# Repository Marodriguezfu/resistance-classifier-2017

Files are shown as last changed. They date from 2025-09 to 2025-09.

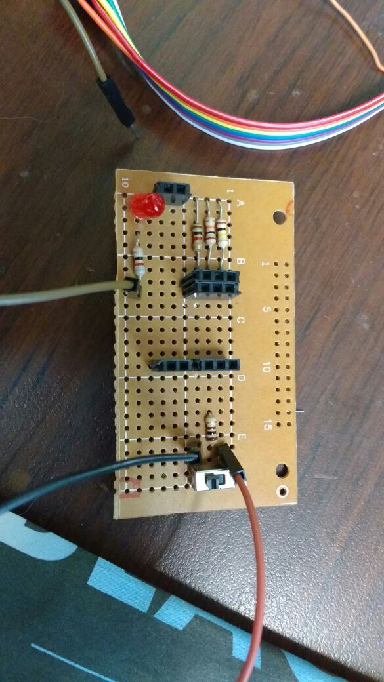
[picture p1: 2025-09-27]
images/Ima3.jpeg

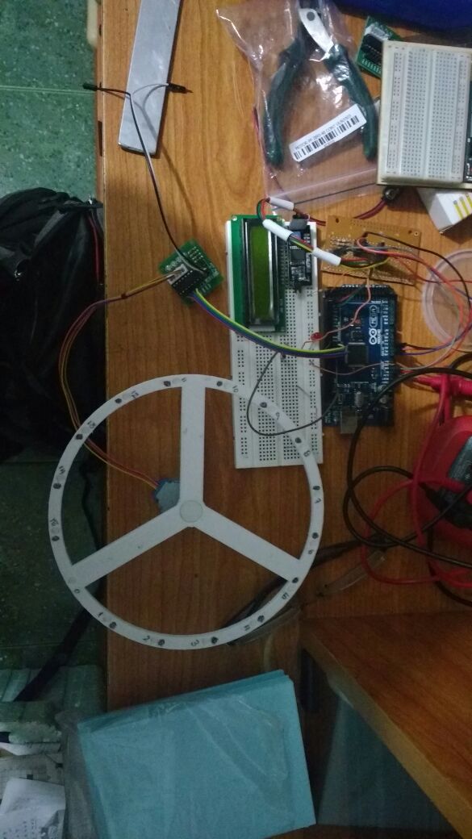
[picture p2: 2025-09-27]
images/Ima1.jpeg

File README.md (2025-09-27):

# Resistance Classifier (2017)

This repository contains the complete work of the **Resistance Classifier Project**, developed in 2017 as part of an engineering workshop at the **Universidad Nacional de Colombia**.  
The goal was to design and implement a device capable of **measuring and classifying resistors automatically** using **Arduino-based circuits**, **stepper motors**, and **3D-printed components**.

---

## 📖 Project Overview

Classifying resistors manually can be tedious due to their color bands and prone to human error (especially for people with visual impairments such as color blindness).  
This project proposed a compact device that could **feed, measure, and sort resistors** into dedicated containers:

1. **Feeding system** – a roller mechanism controlled by a motor that allows one resistor at a time to enter the measurement unit.  
2. **Measuring system** – based on an **Arduino ohmmeter** using voltage dividers and Ohm’s law.  
3. **Classification system** – a rotating rail controlled by a stepper motor, which directs the resistor into the correct bin according to its value.

---

## 🛠️ Features

- Arduino-based ohmmeter to calculate resistor values.  
- Automatic range detection (100 Ω – 820 kΩ).  
- Stepper motor precision control for classification.  
- Mechanical design of roller, rail, and box using **SolidWorks** and intended for 3D printing.  
- LCD display for showing measured resistance and assigned bin.  

---

## 📂 Repository Structure
```
resistance-classifier-2017/
│
├── src/ # Arduino source code
├── docs/ # Reports, guides, and project proposal (PDFs)
├── cad/ # CAD designs (SolidWorks)
├── figures/ # Images, diagrams, and results
├── README.md # Project documentation
└── .gitignore
```

## 📑 Documentation

The full documentation is provided in the `docs/` folder:
- **Project Proposal** – initial justification, design, and planning.  
- **Guides 1–3** – experimental steps with Arduino ohmmeter, CAD design, and stepper.  
- **Reports 1–3** – results of each stage (measurement ranges, CAD design, motor control).  
- **Final Report** – complete description of the device, final assembly, and conclusions.
---

## ⚙️ Hardware & Software Requirements

- **Hardware**
  - Arduino UNO (or compatible board)
  - Breadboard, jumpers, and resistors
  - Stepper motor (28BYJ-48) + ULN2003 driver
  - LCD display
  - 3D-printed mechanical parts (roller, box, rail)

- **Software**
  - Arduino IDE
  - SolidWorks (for CAD design)

---

## 🚀 How to Run

1. Connect the circuit as described in the `docs/Informe Final.pdf`.  
2. Open the Arduino IDE and upload the source code from `src/`.  
3. Place resistors into the roller mechanism.  
4. The system will measure and classify each resistor, showing results on the LCD.  

---

## 📊 Results

- Achieved automatic classification in ranges from **100 Ω up to 820 kΩ** with predefined tolerance.  
- Demonstrated integration of electronics, programming, and mechanical design.  
- Highlighted the importance of cost optimization in 3D printing (not all parts were fabricated).  

---

## 👥 Authors

- Julián Camilo Casallas Villamil  
- José Fernando Murcia Rincón  
- Daniel Camilo Peña Pabón  
- **Miguel Ángel Rodríguez Fuentes**  

Universidad Nacional de Colombia, 2017.

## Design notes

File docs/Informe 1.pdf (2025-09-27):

# Informe 1: Experimentación con el Óhmetro de Arduino

Casallas Villamil Julián Camilo, Murcia Rincón José Fernando, Peña Pabón Daniel Camilo, Rodríguez Fuentes Miguel Ángel
jcasallasv@unal.edu.co, jmurciar@unal.edu.co, dpenap@unal.edu.co, marodriguezfu@unal.edu.co

### Universidad Nacional de Colombia Grupo de Taller: 3 - Equipo de Trabajo: 4

I. RESUMEN

Con la primer práctica del clasificador de resistencias se busca establecer los rangos de funcionamiento del proyecto, así como los ajustes que se deben hacer a la idea original.

II. PALABRAS CLAVES

Divisor de voltaje, resistencias, Ley de Ohm, Arduino.

III. INTRODUCCIÒN

Empleando una placa de Arduino y dos resistencias es posible idear un óhmetro muy básico fundamentado en la ley de ohm y en el divisor de voltaje. Por medio de este óhmetro rudimentario, se pueden hacer mediciones básicas para algunas resistencias. Sin embargo, esto no es verídico para resistencias muy pequeñas o muy grandes.

IV. | MARCO TEÓRICO
1.1. Ley | de | Ohm:

Esta ley fundamental en electricidad y electrónica, establece la relación existente entre la tensión (V), la corriente (I) y la resistencia (R) donde esta primera es directamente proporcional a las dos siguientes. La fórmula general se escribe así:
V = I * R | (1)
1.2. Divisor | de | Voltaje
En un circuito eléctrico un divisor de voltaje (tensión) es el que reparte en una o más impedancias conectadas en serie la tensión de una fuente
El circuito de un divisor de voltaje se ve de esta manera:

Figura 1.

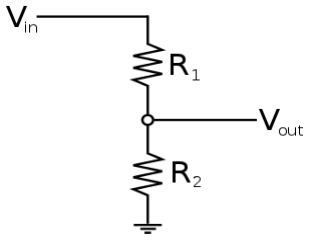
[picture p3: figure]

Esquema divisor de voltaje [1]

1.3. Introducción | básica | a | Arduino
Arduino puede referirse a las placas producidas por la compañía italiana homónima programables por su propio software (Arduino IDE). Estas placas vienen
equipadas | con | un | microcontrolador | o
microprocesador de arquitectura variable, varias entradas y/o salidas (E/S), analógicas y digitales. Estas dos anteriores características (arquitectura del CPU y cantidad de E/S) dependen del modelo del Arduino.[2]

El software necesario para controlar dichas placas (Arduino IDE) consiste de tres bloques de código el primero en el que se inicializan las variables del programa, el segundo (setup) que se ejecuta una sola vez que es donde se configuran los pines del Arduino y el tercero (loop) que se ejecuta perpetuamente es la parte funcional y lógica del código. A continuación se muestra el código para un led parpadeando en el Arduino.[2]

// the setup function runs once when you press reset or power the board
void setup | ( | ) {
// initialize digital pin LED_BUILTIN as an output. pinMode(LED_BUILTIN, OUTPUT);

}
// the loop function runs over and over again forever void loop() {
digitalWrite(LED_BUILTIN, HIGH); // turn the LED on (HIGH is the voltage level)
delay(1000); | // wait for a second
digitalWrite(LED_BUILTIN, LOW); // turn the LED of by making the voltage LOW
delay(1000); | // wait for a second
}
[3]

### Valores de Resistencias comerciales:

Banda 1 | Banda 2 | Banda 3
1 | 0
1 | 1
1 | 2
1 | 3
1 | 5
1 | 6
1 | 8
2 | 0
2 | 2
2 | 4
2 | 7
3 | 0
3 | 3
3 | 6
3 | 9
4 | 3
4 | 7
5 | 1
5 | 6
6 | 2

De 10

-1 a 10

6

6 | 8
7 | 5
8 | 2
9 | 1

### Tabla 1. Valores de resistencias comerciales

V. PARTE I: MONTAJE DEL CIRCUITO EN ARDUINO

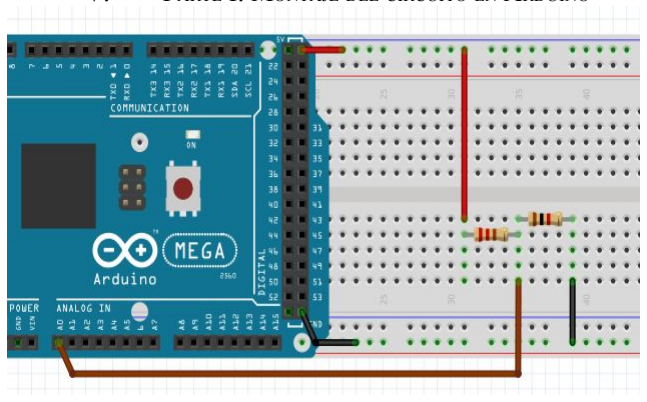
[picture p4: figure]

Figura 2. Montaje divisor de voltaje y Arduino

Tras realizar el montaje de las resistencias, lo que prosiguió fue la realización del código para calcular el valor de la resistencia. Para este cálculo, se emplea el siguiente código:

int analogPin = 0;

int raw = 0;

double Vin = 4.98;

double Vout = 0;

double R1 = 996;

double R2 = 0;

void setup () {

Serial.begin (9600);

}

void loop () {

raw = analogRead(analogPin);

if (raw) {

Serial.print("Raw: ");

Serial.println(raw);

Vout = 5 - ((raw*Vin) / 1023);

Serial.print ("Raw*Vin: ");

Serial.println (raw * Vin);

R2 = Vout/((Vin-Vout)/R1);

Serial.print("Vout: ");

Serial.println(Vout);

Serial.print("R2: ");

Serial.println(R2);

delay(1000);

}

}

VI. PARTE II: MEDICIÓN DE LOS VALORES MÍNIMOS

Una vez todo ensamblado, comenzamos a tomar resistencias variadas en los órdenes de 100 Ω a 1 M Ω , con resistencias fijas de 1000 Ω a 100000 Ω llegando así a la siguiente tabla:

Resistencia Fija ( Ω ) | Rango Mínimo ( Ω ) | Rango Máximo ( Ω )
1000 | 100 | 5600
10000 | 820 | 82000
100000 | 6800 | 820000
Tabla 2. Rangos Max y Min con resistencia fija.

con los valores obtenido en la tabla 2. podemos conocer de antemano los rangos bases con los que debemos trabajar en el proyecto.

VII. CONCLUSIONES:

- La utilización de un divisor de voltaje con un Arduino, resulta en mediciones imprecisas en los extremos del rango de resistencias comerciales.
- El limitar el rango de operación de un dispositivo es vital para un proceso de desarrollo sin baches.

VIII. REFERENCIAS

[1] L. Robert Boylestad, Introducción al análisis de circuitos, 12va ed.., Pearson Educación, 1998, pp. 348,354,355.
[2] D. Hugh Young, Física Universitaria, 13va ed., PEARSON, 2013, p.438.
[3] L. Thomas Floyd, Principios de circuitos eléctricos, 8va ed., PEARSON, 2007, p. 443.
[4] K. charles Alexander, Fundamentos de circuitos eléctricos, 3ra ed, Mc Graw Hill, p.176.

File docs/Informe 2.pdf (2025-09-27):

# Informe 2: Diseño estructura física clasificador de resistencias

Casallas Villamil Julián Camilo, Murcia Rincón José Fernando, Peña Pabón Daniel Camilo, Rodríguez Fuentes Miguel Ángel
jcasallasv@unal.edu.co, jmurciar@unal.edu.co, dpenap@unal.edu.co, marodriguezfu@unal.edu.co

### Universidad Nacional de Colombia Grupo de Taller: 3 - Equipo de Trabajo: 4

I. RESUMEN

Con esta segunda práctica pretendemos realizar el diseño para posterior impresión del clasificador de resistencias. Esto con el fin de mostrar un producto casi terminado para una posible comercialización o distribución del mismo

II. PALABRAS CLAVES

CAD, Impresión 3D

III. INTRODUCCIÒN

Dentro del campo de la ingeniería se hace casi imprescindible el uso de algún tipo de herramienta computacional con el fin de darle vida a los proyectos que se tienen en mente, en este caso hablamos del uso del CAD como herramienta de diseño en tercera dimensión con la cual realizaremos el diseño de la estructura del clasificador de resistencias.

IV. | MARCO TEÓRICO
1. Diseño | 3D:

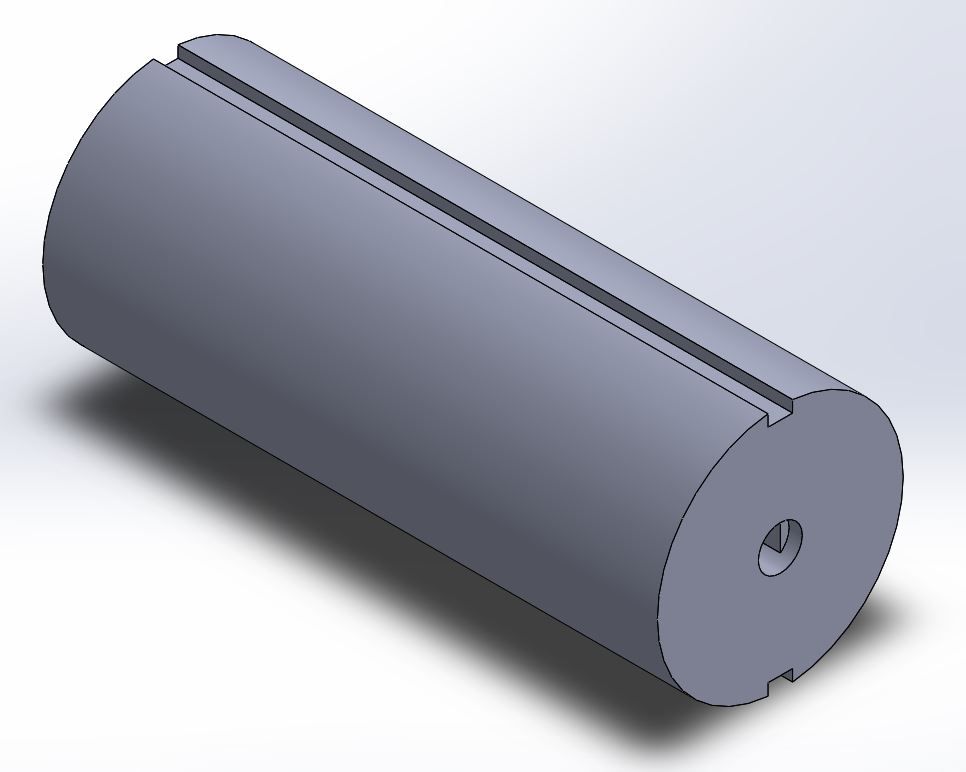
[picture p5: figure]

El diseño en 3D consiste en proporcionar a un objeto digital, creado mediante programas y softwares especiales para ello, las tres dimensiones (profundidad, anchura y longitud) que tiene todo elemento en la vida real. A la hora de realizarlo con los medios informáticos pertinentes y teniendo en cuenta su posterior impresión, el conformado de la pieza debe descomponerse en operaciones sencillas, optando por figuras geométricas básicas. Una vez se conoce el diseño que se quiere fabricar, hay dos opciones para hacer uso de él, en función de las necesidades que requiera el elemento.[1]
Actualmente encontramos en el mercado diversos software con la capacidad de realizar estos diseños asistidos, y entre los más comunes encontramos:
- AutoCAD
- 3D Max
- Sketchup
- SolidWorks

### 2. SolidWorks:

SolidWorks es un programa de diseño mecánico en 3D con el que se puede crear geometría 3D usando sólidos paramétricos, la aplicación está enfocada a diseño de producto, diseño mecánico, ensambles, y dibujos para taller. SolidWorks diseña de forma que va dejando un historial de operaciones para que puedas hacer referencia a ellas en cualquier momento.[2]

V. PARTE I: DISEÑO DEL RODILLO

La forma básica del rodillo es un cilindro con radio de 1 centímetro el cual irá ajustado en la caja principal del dispositivo a partir de un orificio de encaje. También tendrá por la otra cara el encaje para el motor.

Y finalmente el encaje para las resistencias que caerán de la caja y que posteriormente serán medidas a partir de los rangos medidos en el informe anterior.

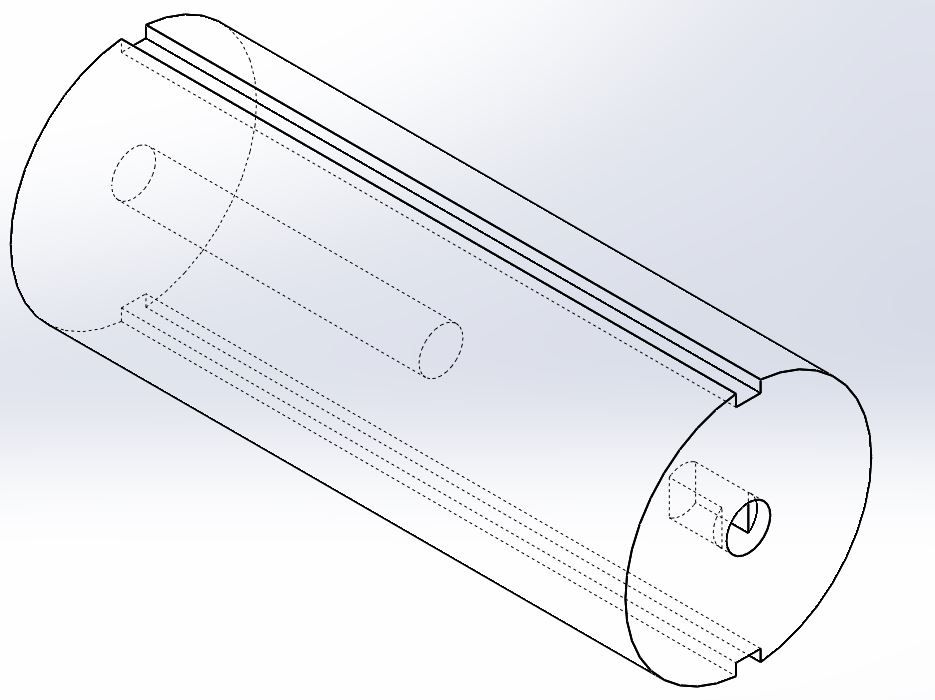
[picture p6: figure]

Figura 1. Forma Final del Rodillo

La figura anterior es el diseño finalizado del rodillo con las características que se necesitaban para llevar a cabo el proyecto. El costo aproximado de la impresión de este elemento es de $14800.

VI. PARTE II: DISEÑO CAJA

Para el diseño de la caja se empezó con la cubierta donde se encontraría el rodillo, la cual irá pegada a una recipiente donde se encontrarán las resistencias.

la cubierta del rodilla poseerá unos orificios los cuales servirán para poner en contacto las resistencias que allí se pongan con algún tipo de lámina conductora con el fin de completar el circuito y así realizar la medida de la resistencia.

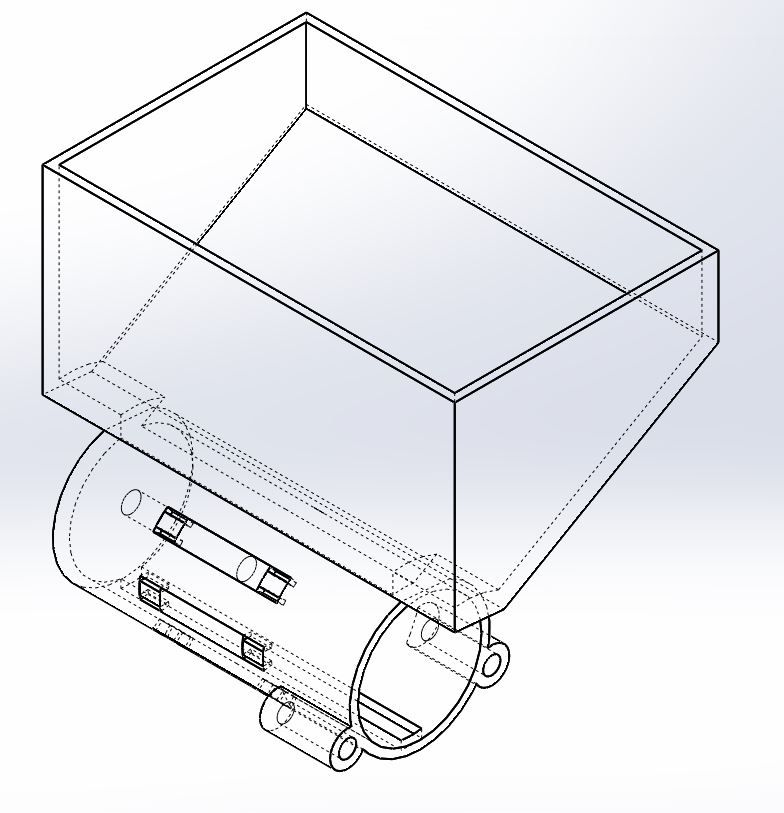
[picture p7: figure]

Figura 2. Forma Final de la caja

El costo aproximado de la impresión de este elemento es de $65500.

VII. PARTE III: DISEÑO DEL RIEL

El riel es la parte más fácil de realizar, solamente es una circunferencia de 9 cm de radio en la cual se dispondrán las distintas cajas.

Para realizar el ajuste más fácil al motor se dispuso de otro pequeño cilindro el cual será la conexión entre este y el riel.

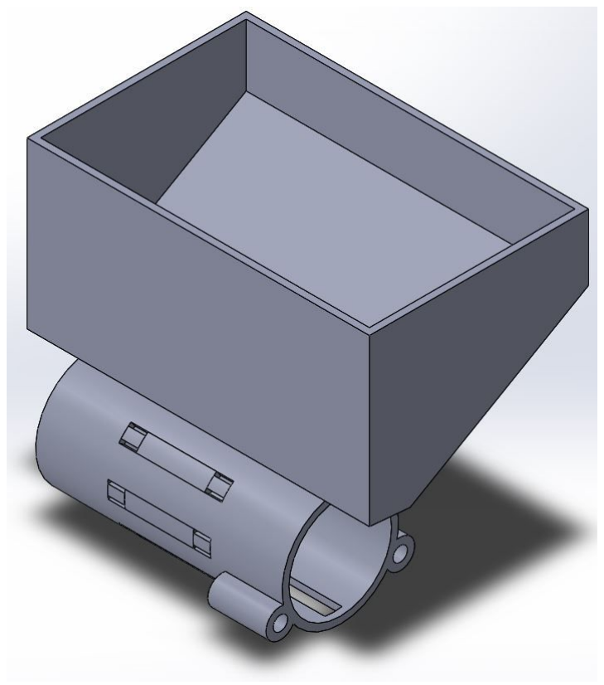
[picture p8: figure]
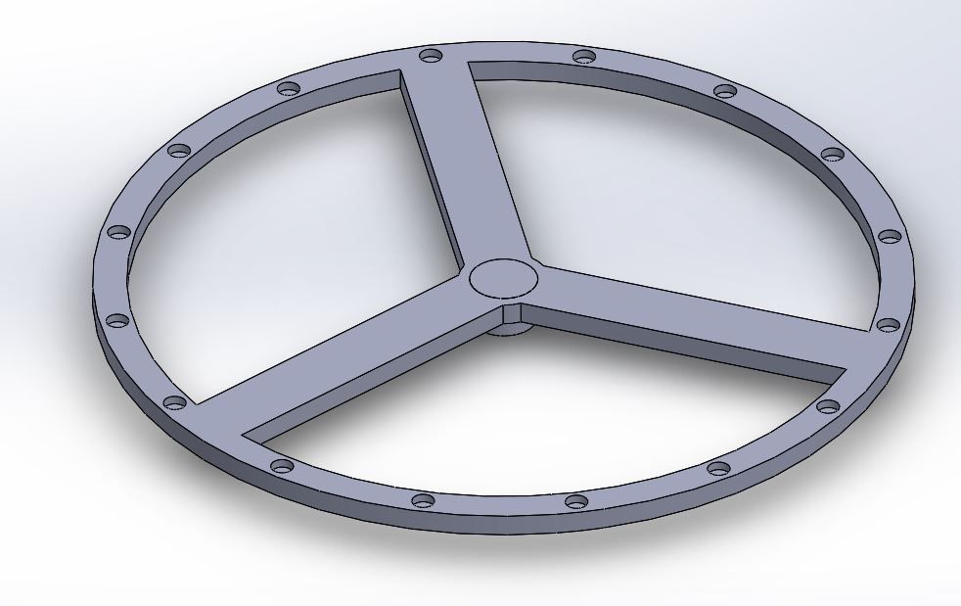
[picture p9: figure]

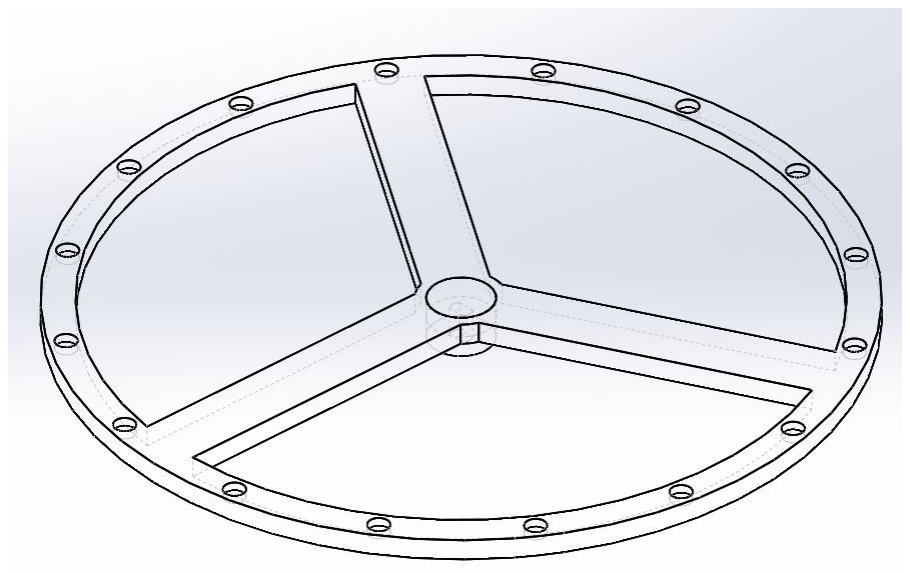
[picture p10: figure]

Figura 3. Forma final del rodillo

El costo aproximado de la impresión de este elemento es de $43300

VIII. CONCLUSIONES:

- Como no es posibles saber la cantidad de material que se usaría en una impresión 3D durante el diseño de las partes, los ajustes para la disminución de material deben hacerse una vez se conoce la cantidad, pero esto provocaría ineficiencia y posibles errores inesperados en el diseño
- El costo total de los elementos es de $123600, por lo cual se hace imposible imprimir las piezas diseñadas para este Informe, solamente nos centraremos en el riel el cual es el que nos dispondrá de las cajas a la hora de medir las resistencias.

IX. REFERENCIAS

[1] Diseño 3d. Componentes y tecnología, obtenido de: http://www.robdosteam.com/wp-content/uploads/2016/10/02.DISEÑO_3D1.p df (http://www.robdosteam.com/wp-content/uploads/2016/10/02.DISE%C3%91O_3D1.pdf)
[2] SolidWorks, obtenido de: http://www.3dcadportal.com/solid-works.html

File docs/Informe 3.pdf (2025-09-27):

# Informe 3: Experimentación motor paso a paso con Arduino

Casallas Villamil Julián Camilo, Murcia Rincón José Fernando, Peña Pabón Daniel Camilo, Rodríguez Fuentes Miguel Ángel
jcasallasv@unal.edu.co, jmurciar@unal.edu.co, dpenap@unal.edu.co, marodriguezfu@unal.edu.co

### Universidad Nacional de Colombia Grupo de Taller: 3 - Equipo de Trabajo: 4

I. RESUMEN

En la práctica se realizara el código adecuado para el ajuste de la rotación de los motores, para el rodillo y el riel, los cuales van a ser fundamentales para el funcionamiento del clasificador de resistencias. El primer motor junto con el rodillo está encargado de obtener las resistencias, para posteriormente con el segundo motor dejar a nuestra disposición la caja en la cual se debe colocar la resistencia.

II. PALABRAS CLAVES

Arduino, motor paso a paso, fuente de alimentación externa.

III. INTRODUCCIÒN

En general usamos los motores paso a paso para el control más preciso del rodillo y riel del clasificador de resistencias. Para el caso específico del riel, generar la cantidad de pasos que debe dar para que logre posicionarse correctamente de la caja X a la Y.

IV. MARCO TEÓRICO

Uno de los principales problemas con los motores CC comunes se da cuando se desea precisión, por ejemplo, cuando requerimos solo dos vueltas, lo cual es imposible con este tipo de motores, ya que no hay forma de saber a ciencia cierta cual es la velocidad de arranque y cuando desconectamos la alimentación el motor seguirá girando por inercia.[1]

Ya que el clasificador de resistencias requiere cierto nivel de precisión, el motor anteriormente mencionado no sera el adecuado para llevar a cabo el mismo, por tal razón se hace necesario el uso de motores paso a paso:

1. Motor | paso | a | paso

Los motores paso a paso no giran libremente por sí mismos, estos avanzan girando por pequeños pasos, generando un mayor torque a bajas velocidades. Siendo este un dispositivo electromagnético que convierte una serie de pulsos eléctricos en desplazamientos angulares, lo que significa que es capaz de girar una cantidad de grados dependiendo de sus entradas de control.

El principio de funcionamiento está basado en un estator construido por varios bobinados en un material ferromagnético y un rotor que puede girar libremente en el estator. Estos bobinados son alimentados uno a continuación del otro y causan un determinado desplazamiento angular que se denomina “paso angular” y es la principal características del motor,[2]

Un tipo de motor paso a paso es el de imán permanente el cual se encuentra como unipolar o bipolar, en nuestro caso utilizaremos el unipolar ya que es el más sencillo y fácil de programar

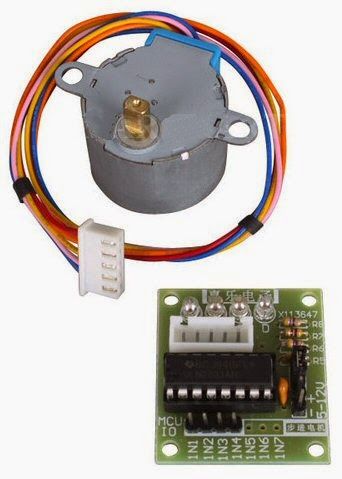
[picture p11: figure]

Figura 1. Motor paso a paso Unipolar y el módulo para conexión con Arduino[3]

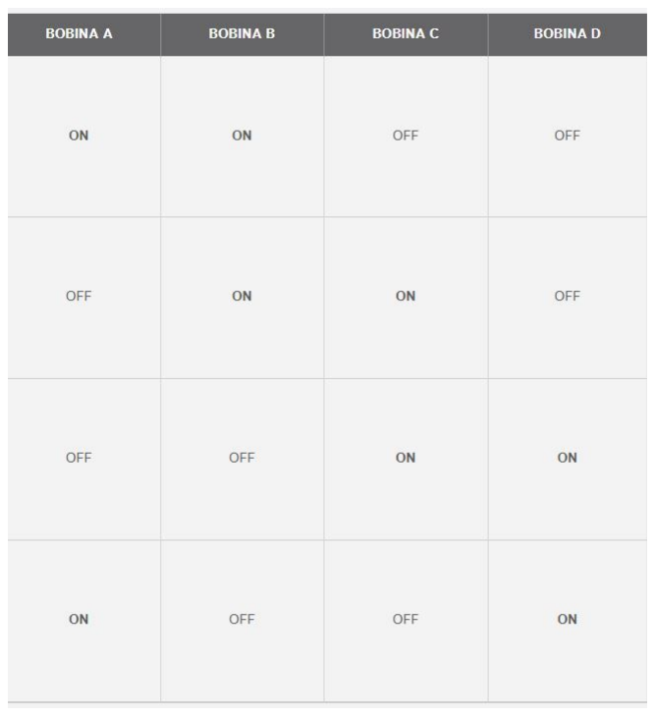
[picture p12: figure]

Figura 2. Activación de embobinado y movimiento del motor.[4]

A partir de la Figura 2. podemos tener un ejemplo de cuales es que deben ser las bobinas a activar para tener un movimiento del motor a secuencia normal.

V. PARTE I: MONTAJE DEL CIRCUITO EN ARDUINO

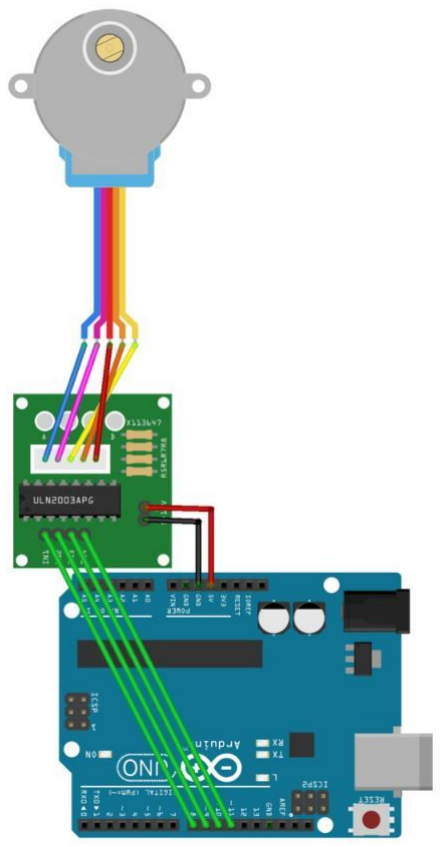
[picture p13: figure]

Figura 3. Montaje del motor con Arduino[5]

VI. PARTE II:CÓDIGO PARA ARDUINO

Necesitamos conocer primero cual es la caja a donde se debe dirigir el riel, de esta manera se implementó el siguiente código:

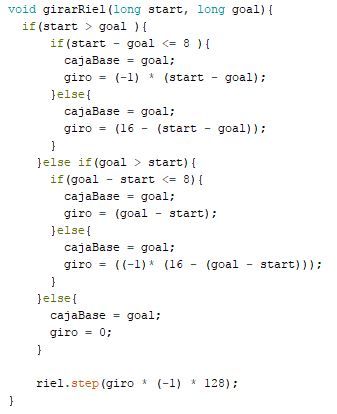
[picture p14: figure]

Figura 4. Código para determinar los giros del motor.

Para poder realizar el giro correcto del motor se va utilizar una librería preestablecida, en donde debemos inicializar los pines a utilizar y el número de pasos. De esta manera complementamos con el siguiente código:

Figura 4. Código para llamar la librería del motor e inicialización.

VII. CONCLUSIONES:

- El motor para el rodillo no fue necesario ya que nos encontramos que no se pudo implementar por completo el diseño en 3D.

VIII. REFERENCIAS

[1] Motores paso a paso, características básicas, obtenido de: http://robots-argentina.com.ar/MotorPP_basico.htm

[2]Motor paso a paso ¿que es y cómo funciona?, obtenido de: http://www.ingmecafenix.com/electricidad-industrial/motor-paso-a-paso/

[3]Tutorial: motor paso a paso con módulo ULN2003, obtenido de: http://elcajondeardu.blogspot.com.co/2015/05/tutorial-motor-paso-paso-con-m odulo.html

[4]Motores paso a paso, conociendo los motores paso a paso, obtenido de: https://www.prometec.net/motores-paso-a-paso/#

[5]Motor paso a paso 28BYJ-48 con Arduino, obtenido de: https://www.prometec.net/motores-paso-a-paso/#

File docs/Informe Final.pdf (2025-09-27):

# Informe Final: Clasificador de Resistencias

Casallas Villamil Julián Camilo, Murcia Rincón José Fernando, Peña Pabón Daniel Camilo, Rodríguez Fuentes Miguel Ángel
jcasallasv@unal.edu.co, jmurciar@unal.edu.co, dpenap@unal.edu.co, marodriguezfu@unal.edu.co

### Universidad Nacional de Colombia Grupo de Taller: 3 - Equipo de Trabajo: 4

I. RESUMEN

En la práctica final se realizaron los últimos ajustes del clasificador de resistencias, con el propósito de que haya una mejor precisión entre los rangos de clasificación de cada resistencia y el movimiento del motor de las cajas del riel. Junto con la programación del LCD para mostrar finalmente la caja y el valor aproximado de la resistencia.

II. PALABRAS CLAVES

Arduino, divisor de voltaje, resistencias, motor paso a paso

III. INTRODUCCIÒN

Para aquellas personas que deben manejar dispositivos electrónicos (generalmente ingenieros electricos, mecatronicos o electricos, etc), es imprescindible el uso de resistencias, de las cuales, en ciertas ocasiones su búsqueda se hace muy engorrosa, no solo al referirnos a las bandas de colores impresas en ellas, sino también para las personas que poseen problemas que les impiden ver claramente el color de las mismas (personas con daltonismo).

IV. | MARCO TEÓRICO
Divisor | de | Voltaje
En un circuito eléctrico un divisor de voltaje (tensión) es el que reparte en una o más impedancias conectadas en serie la tensión de una fuente. El circuito de un divisor de voltaje se ve de esta manera:

Figura 1. Esquema divisor de voltaje [1]

Diseño 3D:

El diseño en 3D consiste en proporcionar a un objeto digital, creado mediante programas y softwares especiales para ello, las tres dimensiones (profundidad, anchura y longitud) que tiene todo elemento en la vida real. A la hora de realizarlo con los medios informáticos pertinentes y teniendo en cuenta su posterior impresión, el conformado de la pieza debe descomponerse en operaciones sencillas, optando por figuras geométricas básicas. Una vez se conoce el diseño que se quiere fabricar, hay dos opciones para hacer uso de él, en función de las necesidades que requiera el elemento.[1]

Motor | paso | a | paso

Los motores paso a paso no giran libremente por sí mismos, estos avanzan girando por pequeños pasos, generando un mayor torque a bajas velocidades. Siendo este un dispositivo electromagnético que convierte una serie de pulsos eléctricos en desplazamientos angulares, lo que significa que es capaz de girar una cantidad de grados dependiendo de sus entradas de control.

El principio de funcionamiento está basado en un estator construido por varios bobinados en un material ferromagnético y un rotor que puede girar libremente en el estator. Estos bobinados son alimentados uno a continuación del otro y causan un determinado desplazamiento angular que se denomina “paso angular” y es la principal características del motor,[2]

Un tipo de motor paso a paso es el de imán permanente el cual se encuentra como unipolar o bipolar, en nuestro caso utilizaremos el unipolar ya que es el más sencillo y fácil de programar


Figura 2. Motor paso a paso Unipolar y el módulo para conexión con Arduino[3]

V. PARTE I: RANGOS

Como se habló en el informe 1. presentado de este proyecto, se realizó el montaje de la Figura 1. con el fin de conocer a partir de un divisor de voltaje la resistencia que usuario deseara. Y nos encontramos que el rango general de trabajo debía ser desde los 100 Ω hasta los 820000 Ω . usando 3 resistencias fijas de 1000 Ω , 10000 Ω y 100000 Ω .

Resistencia Fija ( Ω ) | Rango Mínimo ( Ω ) | Rango Máximo ( Ω )
1000 | 100 | 5600
10000 | 820 | 82000
100000 | 6800 | 820000
Tabla 1. Rangos Max y Min con resistencia fija.

A partir de los valores obtenido en la tabla 1. podemos conocer de antemano los rangos bases con los que debemos trabajar en el proyecto. Además, el código se programó para tener en cuenta el margen de error para el valor de cada resistencia y con eso determina a qué caja corresponde cada una (Tabla 2.)

Arreglo | Valor Comercial | Banda 1 | Banda 2 | Error Min | Error Max | caja
0 | 10 | | | 9,5 | 10,5 | 1
1 | 12 | | | 11,4 | 12,6 | 2
2 | 15 | | | 14,25 | 15,75 | 3
3 | 18 | | | 17,1 | 18,9 | 4
4 | 22 | | | 20,9 | 23,1 | 5
5 | 27 | | | 25,65 | 28,35 | 6
6 | 33 | | | 31,35 | 34,65 | 7
7 | 39 | | | 37,05 | 40,95 | 8
8 | 47 | | | 44,65 | 49,35 | 9
9 | 51 | | | 48,45 | 53,55 | 10
10 | 56 | | | 53,2 | 58,8 | 11
11 | 68 | | | 64,6 | 71,4 | 12
12 | 82 | | | 77,9 | 86,1 | 13
| | | | | | 14
| | | | | | 15
| | | | | | 16
Tabla 2. Valores de las resistencias con el margen de error y su respectiva caja.

Con la Información anterior nos será posible y con mayor facilidad programar el motor paso paso para que nos arroje las cajas de manera adecuada.

VI. PARTE II: DISEÑO 3D

Como concluimos en su respectivo momento, fue necesario descartar la mayor parte de los elementos diseñados ya que el costo de su manufactura era demasiado elevado, por tal razón se decidió realizar solamente el riel y su sujetador al motor. Al final también ayudaría a que el código fuese más simple por tener que programar solamente uno de los dos motores planteados al principio del proyecto

El riel siendo la parte más fácil de realizar, solamente es una circunferencia de 9 cm de radio en la cual se dispondrán de 16 cajas. Las cuales estarán separadas por más o menos 23 grados de diferencia con el fin que la carga y distribución sean equitativas.

Para realizar el ajuste más fácil al motor se dispuso de otro pequeño cilindro el cual será la conexión entre este y el riel.

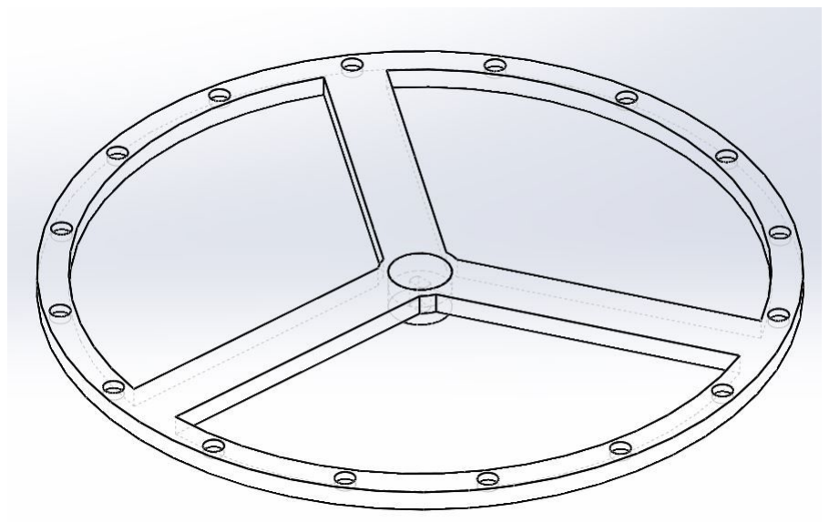
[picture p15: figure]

Figura 3. Forma final del rodillo

El costo aproximado de la impresión de este elemento es de $43300

VII. PARTE III: MOTOR PASO A PASO

Primero se debía hacer la prueba individual del motor con el fin de no afectar de alguna manera el código anteriormente establecido para la clasificación de las resistencias. Por tal razón fue necesario realizar el siguiente montaje.

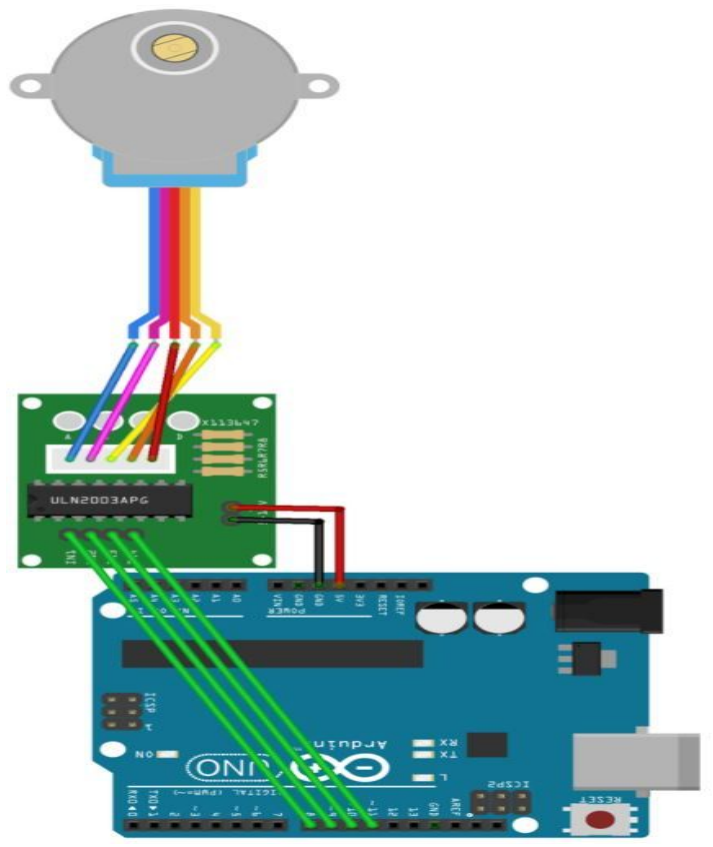
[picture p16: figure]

Figura 4. Montaje del motor con Arduino[4]

Luego necesitamos conocer cual es la caja a donde se debe dirigir el riel, de esta manera se implementó el siguiente código:

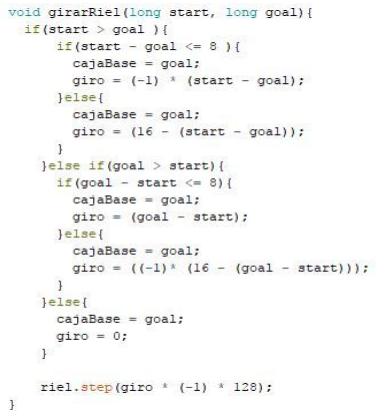
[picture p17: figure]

Figura 5. Código para determinar los giros del motor. Para poder realizar el giro correcto del motor se va utilizar una librería preestablecida, en donde debemos inicializar los pines a utilizar y el número de pasos. De esta manera complementamos con el siguiente código:

Figura 6. Código para llamar la librería del motor e inicialización.

VIII. PARTE III: AJUSTES FINALES

Para finalizar, nos encontramos con la programación del LCD el cual decidimos como lo fue con el motor, utilizar una librería ya preestablecida por Arduino. De esta manera solo era necesario llamar las respectivas funciones para que apareciera el texto en la pantalla del LCD. Q

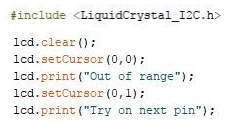
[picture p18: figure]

Figura 7. Ejemplo Codigo LCD

El código final completo puede encontrar en la carpeta adjunta al Informe Final.

Finalmente físicamente el clasificador de resistencias quedó de la siguiente manera.

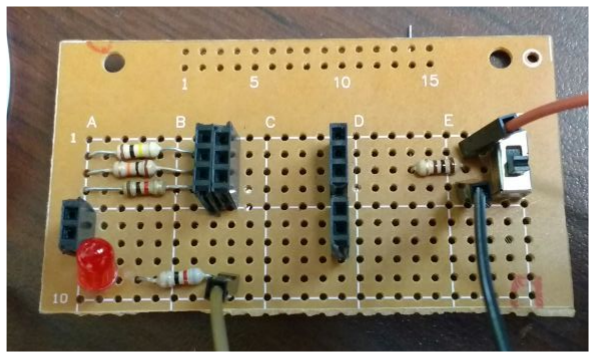
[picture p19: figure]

Figura 8. Base para conexiones con Arduino

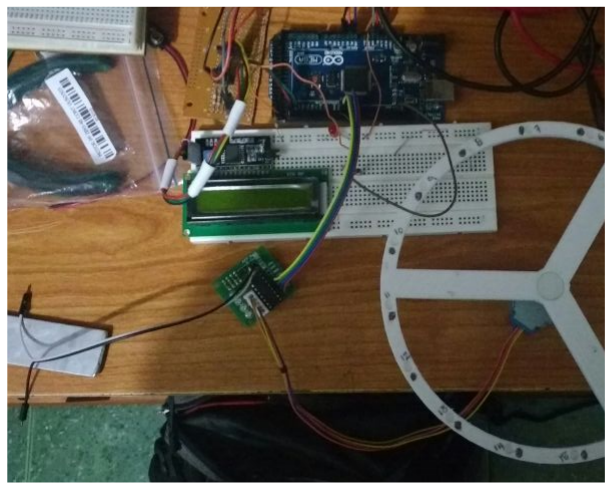
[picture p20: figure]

Figura 9. Montaje Completo del clasificador de resistencias

IX. CONCLUSIONES

- Durante el desarrollo del código hubo muchas modificaciones que generaron retrasos tanto en la medición de los valores como en el funcionamiento de los motores.
- Para lograr una mayor precisión con las lecturas de cada resistencia, fue necesario limitar el valor de las resistencias comerciales que se utilizarían y así mismo se determinó cuál sería el rango mínimo y el rango máximo para clasificar.
- La implementación final del código dio como resultado un código extenso y engorroso, ya que ninguno de los integrantes del grupo había trabajado anteriormente en un proyecto de esta magnitud, dejando plasmadas en ellas la poca experiencia que se tiene del tema.
- Se debió hacer uso de diversos recursos ya presentados en la web, como del mismo Arduino para llevar a cabo de forma más amena el diseño final del clasificador de resistencias.
X. REFERENCIAS
[1] ¿Qué es un divisor de voltaje?, obtenido de: http://www.arduinotutoriales.com/que-es-un-divisor-de-voltaje/
[2] Motor paso a paso ¿que es y cómo funciona?, obtenido de: http://www.ingmecafenix.com/electricidad-industrial/motor-paso-a-paso/ (http://www.ingmecafenix.com/electricidad-industrial/motor-paso-a-paso/)

[3] Tutorial: motor paso a paso con módulo ULN2003, obtenido de: http://elcajondeardu.blogspot.com.co/2015/05/tutorial-motor-paso-paso-con-modulo.html (http://elcajondeardu.blogspot.com.co/2015/05/tutorial-motor-paso-paso-con-modulo.html)
[4] Motor paso a paso 28BYJ-48 con Arduino, obtenido de: https://www.prometec.net/motores-paso-a-paso/#

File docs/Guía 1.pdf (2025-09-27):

# Guía 1: Experimentación con el Ohmetro de Arduino

Casallas Villamil Julián Camilo, Murcia Rincón José Fernando, Peña Pabón Daniel Camilo, Rodríguez Fuentes Miguel Ángel
jcasallasv@unal.edu.co, jmurciar@unal.edu.co, dpenap@unal.edu.co, marodriguezfu@unal.edu.co Universidad Nacional de Colombia Grupo de Taller: 3 - Equipo de Trabajo: 4

Con esta primera guía se espera dar entendimiento de los primeros pasos de nuestro proyecto.

### 1. Objetivo

Realizar la respectiva programación para calcular el valor de una resistencia, independientemente del valor que esta posea desde Arduino y conocer de manera más detallada cuales son los rangos para los cuales el valor obtenido de la resistencia sea el más apropiado.

2. Marco | conceptual
2.1. Ley | de | Ohm
Esta ley fundamental en electricidad y electrónica, establece la relación existente entre la tensión (V), la corriente (I) y la resistencia (R) donde esta primera es directamente proporcional a las dos siguientes. La fórmula general se escribe así:
V = I * R | (1)
2.2. Divisor | de | Voltaje
En un circuito eléctrico un divisor de voltaje (tensión) es el que reparte en una o más impedancias conectadas en serie la tensión de una fuente
El circuito de un divisor de voltaje se ve de esta manera

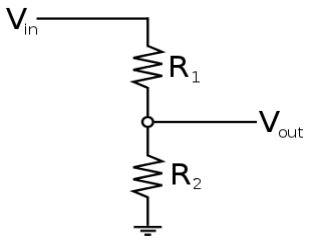
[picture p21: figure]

Figura 1. Esquema divisor de voltaje [1]

2.3. Introducción | básica | a | Arduino

Arduino puede referirse a las placas producidas por la compañía italiana homónima programables por su propio software (Arduino IDE). Estas placas vienen equipadas con un microcontrolador o microprocesador de arquitectura variable, varias entradas y/o salidas (E/S), analógicas y digitales. Estas dos anteriores características (arquitectura del CPU y cantidad de E/S) dependen del modelo del Arduino.[2]

El software necesario para controlar dichas placas (Arduino IDE) consiste de tres bloques de código el primero en el que se inicializan las variables del programa, el segundo (setup) que se ejecuta una sola vez es donde se configuran los pines del arduino y el tercero (loop) que se ejecuta perpetuamente es la parte funcional y lógica del código. A continuación se muestra el código para un led parpadeando en el arduino.[2]

// the setup function runs once when you press reset or power the board
void setup() {
// initialize digital pin LED_BUILTIN as an output. pinMode(LED_BUILTIN, OUTPUT);
}
// the loop function runs over and over again forever
void loop() {
digitalWrite(LED_BUILTIN, HIGH); // turn the LED on (HIGH is the voltage level)
delay(1000); | // wait for a second
digitalWrite(LED_BUILTIN, LOW); // turn the LED off by making the voltage LOW
delay(1000); | // wait for a second
}[3]
2.4. Valores | de | Resistencias | comerciales

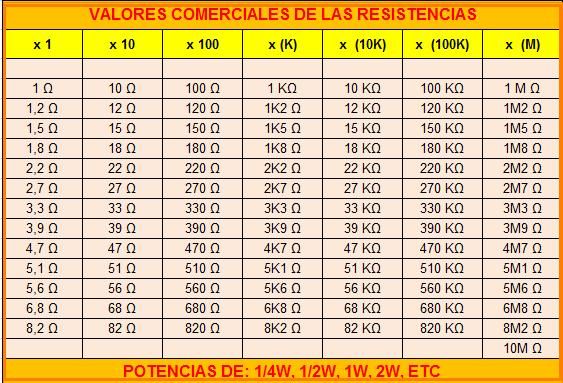
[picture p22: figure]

Figura 2. Tabla de resistencias comerciales[4]

3. Equipos | y | Elementos | necesarios | para | la | práctica
- Placa Arduino (Mini, UNO, MEGA)
- Protoboard
- Jumpers
- Resistencias variadas

### 4. Procedimiento

En la protoboard realice el siguiente montaje:

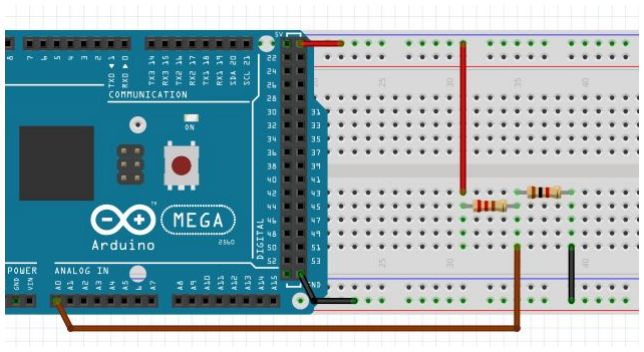
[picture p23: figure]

Figura 2. Montaje de arduino [5]

Posteriormente, compile y suba el siguiente código al arduino. Tenga en cuenta los pines del arduino usados para asignar los valores de estos en el código.

int analogPin= 0;

int raw= 0;

int Vin= 5;

float Vout= 0;

float R1= 1000;

float R2= 0;

float buffer= 0;

void setup()

{

Serial.begin(9600);

}

void loop()

{

raw= analogRead(analogPin);

if(raw)

{

buffer= raw * Vin;

Vout= (buffer)/1024.0;

buffer= (Vin/Vout) -1;

R2= R1 * buffer;

Serial.print("Vout: ");

Serial.println(Vout);

Serial.print("R2: ");

Serial.println(R2);

delay(1000);

}

}

Hay que tener en cuenta que la resistencia fija va a ser cambiada a conveniencia a tal modo que encontremos la que nos arroje con mayor exactitud el valor de la resistencia a medir. Y a partir de la información obtenida estipular los rangos de resistencia que se van a dejar para el proyecto final.

### 5. Referencias

[1] ¿Qué es un divisor de voltaje?, obtenido de: http://www.arduinotutoriales.com/que-es-un-divisor-de-voltaje/
[2] What is Arduino, obtenido de: https://www.arduino.cc/en/Guide/Introduction
[3] Blink, obtenido de: https://www.arduino.cc/en/Tutorial/Blink
[4] Curso: circuitos Eléctricos, obtenido de: http://www.ceduvirt.com/resources/CodigoRes.jpg?timestamp=1279895767632
[5] HOW TO MAKE AN ARDUINO OHM METER., obtenido de: http://www.circuitbasics.com/arduino-ohm-meter/

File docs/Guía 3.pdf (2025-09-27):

# Guía 3: Experimentación de motor paso a paso con arduino

Casallas Villamil Julián Camilo, Murcia Rincón José Fernando, Peña Pabón Daniel Camilo, Rodríguez Fuentes Miguel Ángel
jcasallasv@unal.edu.co, jmurciar@unal.edu.co, dpenap@unal.edu.co, marodriguezfu@unal.edu.co Universidad Nacional de Colombia Grupo de Taller: 3 - Equipo de Trabajo: 4

Con esta tercera guía se espera comprender de mejor manera el funcionamiento de un motor paso a paso y su programación a partir de arduino.

### 1. Objetivo

Comprender el funcionamiento de un motor paso a paso, y a partir de este y los conocimientos adquiridos a lo largo de la práctica anterior, realizar la programación del arduino para el uso de este dispositivo e implementarlo en el proyecto final.

### 2. Marco conceptual

Uno de los principales problemas con los motores CC comunes se da cuando se desea precisión, por ejemplo, cuando requerimos solo dos vueltas, lo cual es imposible con este tipo de motores, ya que no hay forma de saber a ciencia cierta cual es la velocidad de arranque y cuando desconectamos la alimentación el motor seguirá girando por inercia.[1]

Ya que el clasificador de resistencias requiere cierto nivel de precisión, el motor anteriormente mencionado no sera el adecuado para llevar a cabo el mismo, por tal razón se hace necesario el uso de motores paso a paso:

2.1. | Motor | paso | a | paso:

Los motores paso a paso no giran libremente por sí mismos, estos avanzan girando por pequeños pasos, generando un mayor torque a bajas velocidades. Siendo este un dispositivo electromagnético que convierte una serie de pulsos eléctricos en desplazamientos angulares, lo que significa que es capaz de girar una cantidad de grados dependiendo de sus entradas de control.

El principio de funcionamiento está basado en un estator construido por varios bobinados en un material ferromagnético y un rotor que puede girar libremente en el estator. Estos bobinados son alimentados uno a continuación del otro y causan un determinado desplazamiento angular que se denomina “paso angular” y es la principal características del motor,[2]

Un tipo de motor paso a paso es el de imán permanente el cual se encuentra como unipolar o bipolar, en nuestro caso utilizaremos el unipolar ya que es el más sencillo y fácil de programar

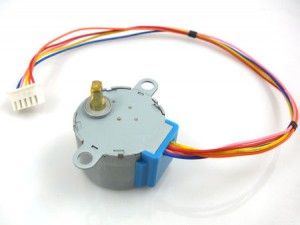
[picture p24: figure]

Figura 1. Motor paso a paso Unipolar

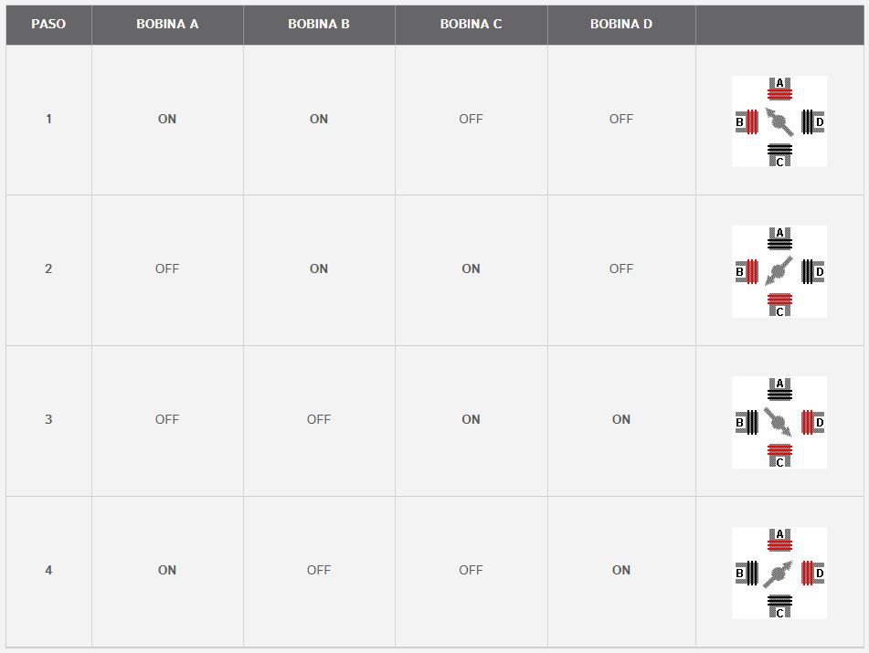
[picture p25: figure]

Figura 2. Activación de embobinado y movimiento del motor

A partir de la Figura 2. podemos tener un ejemplo de cuales es que deben ser las bobinas a activar para tener un movimiento del motor a secuencia normal.[3]

3. Equipos | y | Elementos | necesarios | para | la | práctica
- Placa Arduino (Mini, UNO, MEGA)
- Protoboard
- Jumpers
- Resistencias variadas
- Motor paso a paso

### 4. Referencias

[1] Motores paso a paso, características básicas, obtenido de: http://robots-argentina.com.ar/MotorPP_basico.htm

[2]Motor paso a paso ¿que es y cómo funciona?, obtenido de: http://www.ingmecafenix.com/electricidad-industrial/motor-paso-a-paso/

[3]Motores paso a paso, conociendo los motores paso a paso, obtenido de: https://www.prometec.net/motores-paso-a-paso/#

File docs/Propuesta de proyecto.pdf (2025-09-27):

# Propuesta de proyecto: Clasificador de Resistencias

Casallas Villamil Julián Camilo, Murcia Rincón José Fernando, Peña Pabón Daniel Camilo, Rodríguez Fuentes Miguel Ángel
jcasallasv@unal.edu.co, jmurciar@unal.edu.co, dpenap@unal.edu.co, marodriguezfu@unal.edu.co

### Universidad Nacional de Colombia Facultad de Ingeniería / Departamento de Eléctrica y Electrónica Grupo de Taller: 3 - Equipo de Trabajo: 4

I. JUSTIFICACIÓN

La tarea de clasificar resistencias es tediosa para cualquiera, teniendo que emplear tanto la tabla del código de bandas en conjunto con la fatiga visual que causa el observar detalladamente los dudosos colores de las bandas. Por esta razón, se propone diseñar un dispositivo capaz de realizar esta simple, pero extenuante tarea. A groso modo, el clasificador usaría un óhmetro basado en Arduino para medir la resistencia que se le provee por medio de un sistema de alimentación, para así saber su valor y poder depositarla al contenedor respectivo que se ubicará alrededor del sistema de medición. De manera compacta, este dispositivo estaría disponible sobre cualquier mesa de trabajo electrónico para facilitar la implementación de resistencias en un circuito.

II. DISEÑO

El sistema contará con tres subsistemas: alimentación, medición y clasificación.

- Sistema de Alimentación:

Se dispondrá un cartucho recto donde las resistencias a medir se colocar de tal manera que queden a lo largo. Esto permitirá que por acción de la gravedad bajen hacia un rodillo con surcos sobre su superficie, permitiendo la entrada de una resistencia a la vez al sistema de medición. Este rodillo será accionado por un servomotor controlado por un arduino.

- Sistema de Medición:

El valor de las resistencias será medido empleando un circuito básico cuyo diagrama se indica abajo. Para calcular el valor de la resistencia ingresada, se emplea la ley de voltajes de Kirchhoff y el cálculo de resistencias equivalentes en un circuito. Al comparar el voltaje de entrada con el de salida, tomado después de R1, el arduino es capaz de saber que voltaje se presenta en la resistencia a medir. Una vez conocido este voltaje, se puede calcular la resistencia por medio de ley de Ohm. [1]

- Sistema de Clasificación:

Alrededor de la unidad principal donde se ubicaran los sistemas de alimentación y medición se dispondrá de un sistema de rieles sobre el cual se ubicaran contenedores para las diferentes resistencias. Por medio de un servo-motor los rieles se desplazan acorde a donde se necesita depositar la resistencia medida.

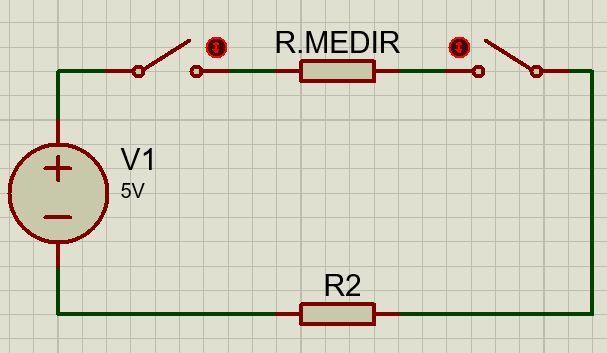
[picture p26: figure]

Figura 1. Circuito básico del Proyecto

III. CONOCIMIENTO Y HABILIDADES NECESARIAS

Para el desarrollo del clasificador de resistencias se necesitan conocimientos en programación de arduino, control de servomotores empleando transistores, conocimientos básicos de diseño e impresión 3d para la impresión de componentes específicos y conocimientos de métodos para emplear rieles al sistema de clasificación.

Dentro de las habilidades necesarias están las de manejo de materiales para ensamblaje posterior a impresión 3D y capacidad de ajustes precisos a el dispositivo y su carcasa en su etapa final. A su vez, habilidades de soldadura y de diseño de circuitos simplificados puede necesitar para simplificar el proyecto en su última versión.

Para el aprendizaje de estos conocimientos y habilidades se depende de la comunidad maker en internet para así poder visualizar varios tutoriales y blogs de Arduino para afianzar conocimientos básicos de la plataforma. En cuanto al modelado e impresión 3D se puede tanto contar con tutoriales en línea como con asesoría de expertos. la parte de rieles puede emplearse también desde tutoriales en línea.

Para adquirir las habilidades de ensamblaje se cuenta con cursos presenciales o virtuales de desarrollo de equipos impresos a 3D. Lo mismo ocurre con la soldadura y simplificación de circuitos, contando con la basta cantidad de cursos y tutoriales ofrecidos en línea de manera gratuita.

IV. PLANEACIÓN

Para lograr desarrollar el dispositivo a tiempo, la preparación en las habilidades y conocimientos faltantes en el grupo de trabajo debe empezarse lo antes posible. A medida que se finalizan las prácticas pre-establecidas para la asignatura, se espera alcanzar un nivel de suficiencia en las áreas en las que el grupo no puede valerse aún. Debido a que no todos los integrantes poseen una misma facilidad para realizar diferentes tareas, se optimizará el tiempo asignando roles concretos a cada integrante del grupo teniendo en cuenta sus fortalezas y debilidades, implementando las primeras en las tareas más aptas para cada individuo, y teniendo en cuenta las segundas para ser solucionadas desde las fortalezas de otro integrante del grupo. Una vez haya disponibilidad de tiempo durante las prácticas restantes en el semestre, se buscará avanzar en cada sistema para así finalizando el semestre disponer de por lo menos un mes para unificar los tres sistemas ya diseñados. Posterior a este proceso de unión de sistemas, el tiempo restante se emplea para la afinación y el detalle del producto final.

Una constante supervisión de progreso de las tareas de cada integrante garantizará que el proyecto no se estanque en ninguna etapa.

V. REFERENCIAS
[1] Circuit Basics (2017, Agosto 16), How to make an Arduino Ohm Meter. Circuit Basics. [En Linea] Disponible:
http://www.circuitbasics.com/arduino-ohm-meter/

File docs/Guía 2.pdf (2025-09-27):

# Guía 2: Diseño estructural física del proyecto final

Casallas Villamil Julián Camilo, Murcia Rincón José Fernando, Peña Pabón Daniel Camilo, Rodríguez Fuentes Miguel Ángel
jcasallasv@unal.edu.co, jmurciar@unal.edu.co, dpenap@unal.edu.co, marodriguezfu@unal.edu.co Universidad Nacional de Colombia Grupo de Taller: 3 - Equipo de Trabajo: 4

Con esta segunda guía se espera realizar el diseño mecánico del proyecto a partir de un CAD.

### 1. Objetivo:

- Diseñar los componentes mecánicos que harán parte del clasificador de resistencias.
- Conocer las limitaciones técnicas del dispositivo.
2. Marco | conceptual:
2.1. | Diseño | 3D:
El diseño en 3D consiste en proporcionar a un objeto digital, creado mediante programas y softwares especiales para ello, las tres dimensiones (profundidad, anchura y longitud) que tiene todo elemento en la vida real.

A la hora de realizarlo con los medios informáticos pertinentes y teniendo en cuenta su posterior impresión, el conformado de la pieza debe descomponerse en operaciones sencillas, optando por figuras geométricas básicas. Una vez se conoce el diseño que se quiere fabricar, hay dos opciones para hacer uso de él, en función de las necesidades que requiera el elemento.[1]

Actualmente encontramos en el mercado diversos software con la capacidad de realizar estos diseños asistidos, y entre los más comunes encontramos:
- AutoCAD
- 3D Max
- Sketchup
- SolidWorks

### 2.2. SolidWorks:

SolidWorks es un programa de diseño mecánico en 3D con el que se puede crear geometría 3D usando sólidos paramétricos, la aplicación está enfocada a diseño de producto, diseño mecánico, ensambles, y dibujos para taller. SolidWorks diseña de forma que va dejando un historial de operaciones para que puedas hacer referencia a ellas en cualquier momento.[2]

3. Equipos | y | Elementos | necesarios | para | la | práctica
- Computador con CAD (No especificado)

### 4. Procedimiento

A partir de los conocimientos que se posean sobre el CAD a trabajar, implementar el diseño de cada una de las partes, las cuales son las fundamentales para el debido funcionamiento del clasificador de resistencias; las respectivas medidas, acotaciones o características se deben establecer en el mismo momento de la realización del diseño.

Las partes que deben ser diseñadas son las siguientes:
- Rodillo con orificios para una o varias resistencias
- Prisma rectangular hueco
- Caja con salida única
- Riel

### 5. Referencias

[1]Diseño 3d. Componentes y tecnología, obtenido de: http://www.robdosteam.com/wp-content/uploads/2016/10/02.DISEÑO_3D1.pdf [2]SolidWorks, obtenido de: http://www.3dcadportal.com/solid-works.html

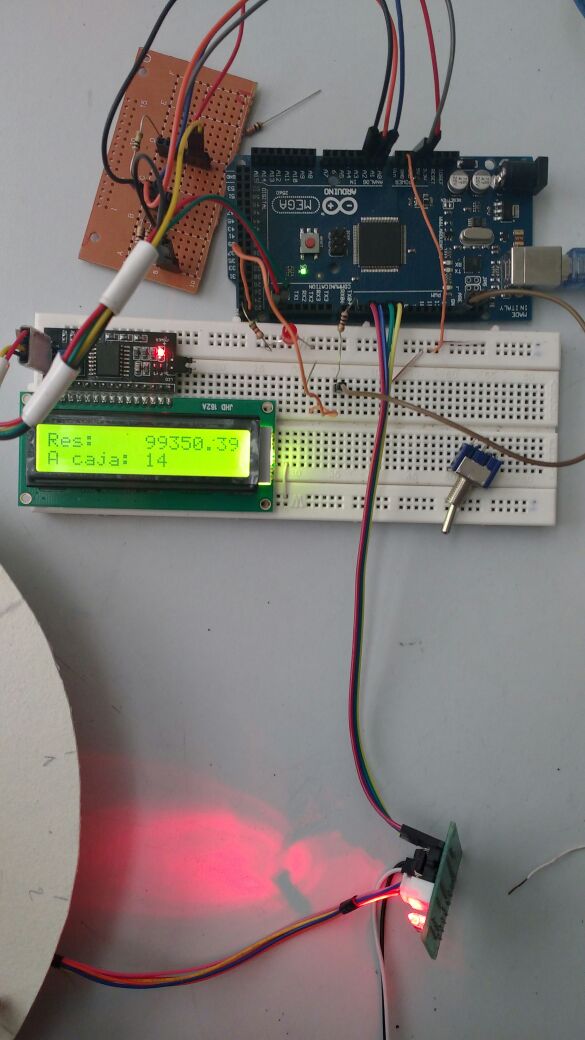
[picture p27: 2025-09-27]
images/Ima2.jpeg

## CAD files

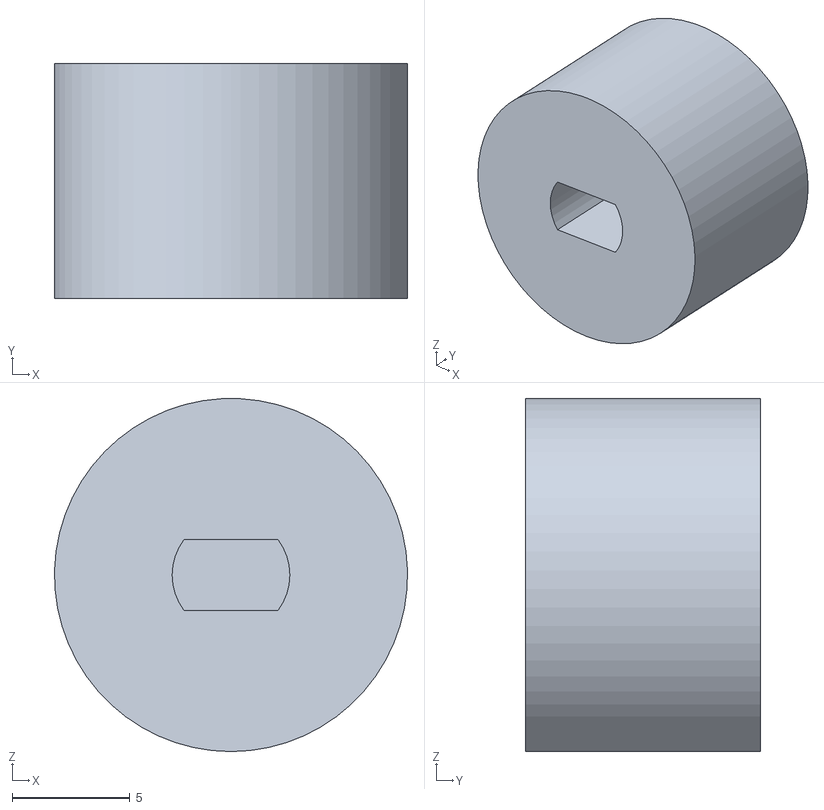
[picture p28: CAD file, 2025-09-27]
data/baseRiel.STL
15.0 x 10.0 x 15.0

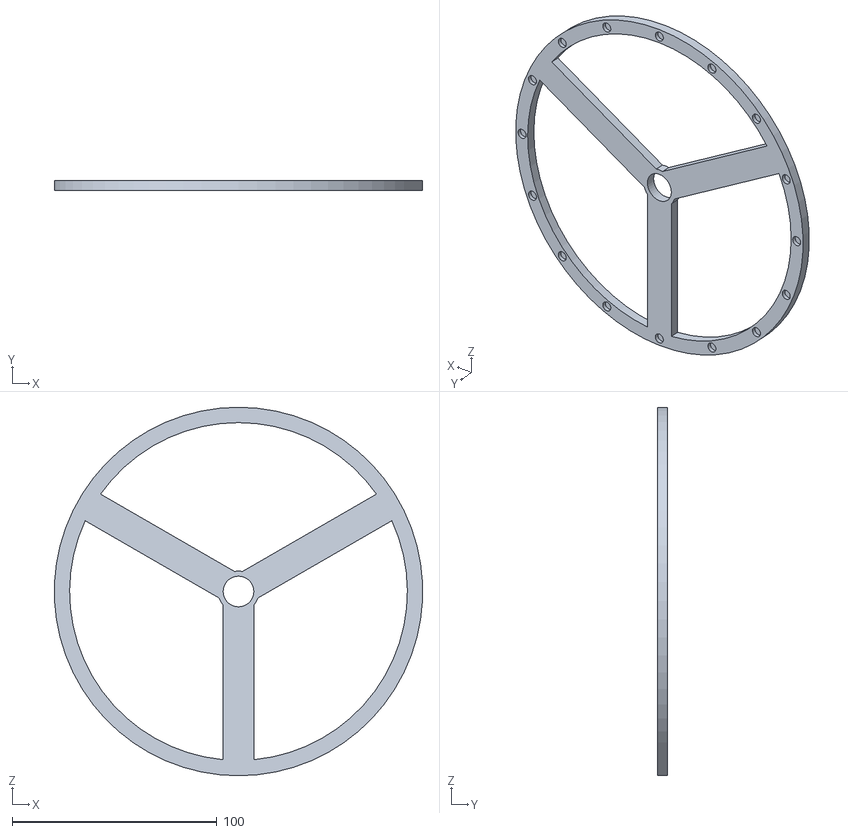
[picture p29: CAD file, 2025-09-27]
data/Riel.STL
179.8 x 5.00 x 180.0

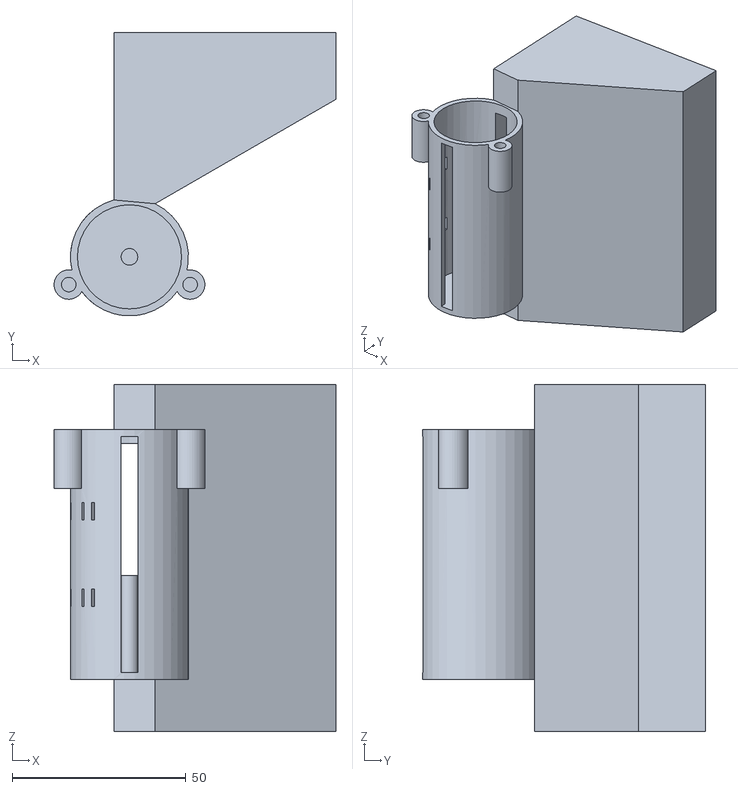
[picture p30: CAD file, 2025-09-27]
data/caja.STL
81.2 x 81.6 x 100.0

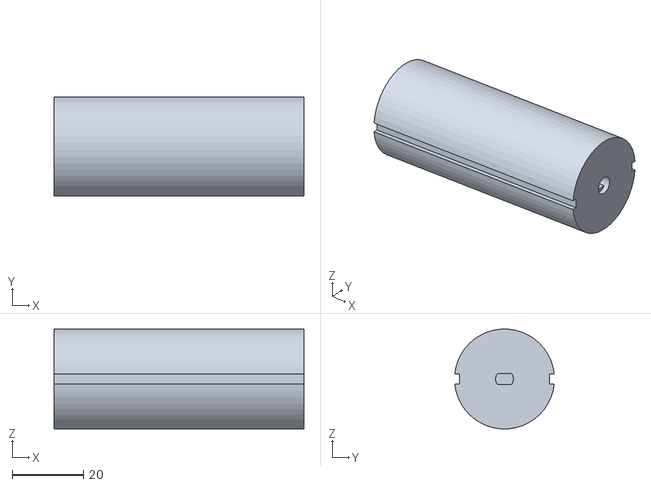
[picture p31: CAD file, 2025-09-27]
data/Rodillo.STL
70.0 x 27.9 x 27.9

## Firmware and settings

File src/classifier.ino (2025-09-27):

#include <Stepper.h>
#include <math.h>
#include <Wire.h>
#include <LiquidCrystal_I2C.h>

LiquidCrystal_I2C lcd (0x27, 2, 1, 0, 4, 5, 6, 7, 3, POSITIVE);

Stepper rodillo (32, 30, 32, 31, 33);
Stepper riel (32, 36, 38, 37, 39);

unsigned int pin1 = A0, pin2 = A1, pin3 = A2, raw1 = 0, raw10 = 0, raw100 = 0, cont = 0,  auR, cajaBase = 1, aux = 1;
double Vin = 4.98, Vout = 0, fija1 = 1019, fija2 = 10040, fija3 = 98000, auxR;

double resistor[13] = {0.1, 0.12, 0.15, 0.18, 0.22, 0.27, 0.33, 0.39, 0.47, 0.51, 0.56, 0.68, 0.82};
double valores[13][2];

boolean enRango, clasificable, adentro;

double inRange(int rango) {

  double R;

  switch (rango) {

    case 1:
      Vout = Vin - ((raw1 * Vin) / 1023);
      R = (Vout * fija1) / (Vin - Vout);
      Serial.println("\nPin 1");
      break;
    case 2:
      Vout = Vin - ((raw10 * Vin) / 1023);
      R = (Vout * fija2) / (Vin - Vout);
      Serial.println("\nPin 2");
      break;
    case 3:
      Vout = Vin - ((raw100 * Vin) / 1023);
      R = (Vout * fija3) / (Vin - Vout);
      Serial.println("\nPin 3");
      break;

  }

  Serial.print("Raw x Vin: ");
  Serial.println(1023 * (Vin - Vout));
  Serial.print("Vout: ");
  Serial.println(Vout);
  Serial.print("Resis: ");
  Serial.println(R);

  delay(1000);
  return R;

}

void girarRodillo(int grados) {

  //Lo ideal es que grados sea un múltiplo de 45, pero con cualquier número debería funcionar igual.

  Serial.print("Grados: ");
  Serial.println(grados);
  int giro = (int)((grados * 512) / 45); //2048/360
  Serial.print("Giro: ");
  Serial.println(giro);
  rodillo.step(giro);
}

void girarRiel(int cajaIni, int cajaFin) {

  int giro;

  if (cajaIni > cajaFin ) {
    if (cajaIni - cajaFin <= 8 ) {
      cajaBase = cajaFin;
      giro = (-1) * (cajaIni - cajaFin);
    } else {
      cajaBase = cajaFin;
      giro = (16 - (cajaIni - cajaFin));
    }
  } else if (cajaIni < cajaFin) {
    if (cajaFin - cajaIni <= 8) {
      cajaBase = cajaFin;
      giro = (cajaFin - cajaIni);
    } else {
      cajaBase = cajaFin;
      giro = ((-1) * (16 - (cajaFin - cajaIni)));
    }
  } else {
    cajaBase = cajaFin;
    giro = 0;
  }

  riel.step(giro * 128);
}

void rangos (int aux) {

  Serial.print("aux: ");
  Serial.println(aux);

  for (int x = 0; x < 13; x++) {
    for (int y = 0; y < 2 ; y++) {
      if (y == 0)
        valores[x][y] = (resistor[x] * aux - ((resistor[x] * aux) * 0.05));
      else
        valores[x][y] = (resistor[x] * aux + ((resistor[x] * aux) * 0.05));
    }
  }

  for (int x = 0; x < 13; x++) {
    for (int y = 0; y < 2 ; y++) {
      if (y == 0) {
        Serial.print("valores[");
        Serial.print(x);
        Serial.print("][");
        Serial.print(y);
        Serial.print("]: ");
        Serial.println(valores[x][y]);
      } else {
        Serial.print("valores[");
        Serial.print(x);
        Serial.print("][");
        Serial.print(y);
        Serial.print("]: ");
        Serial.println(valores[x][y]);
      }
    }
  }
}

boolean imprimidor(int mult, int pin) {

  boolean dentroRango = false;
  double Resis = 0;

  for (int x = 0; x < 13; x++) {
    if (auxR >= valores[x][0] && auxR <= valores[x][1]) {
      Serial.print("El valor de la resistencia es: ");
      Resis = resistor[x] * mult;
      Serial.println(Resis);

      girarRiel(cajaBase, x);

      delay(500);
      pin = 4 - pin;
      girarRodillo(pin * 45);
      dentroRango = true;
      break;
    }
  }
  return dentroRango;
}

void setup() {
  Serial.begin(9600);
  lcd.begin(16, 2);

  lcd.clear();
  lcd.print("Iniciando...");

  rodillo.setSpeed(800);
  girarRodillo(360);

  riel.setSpeed(1200);
}

void loop() {
  double caster = 0;

  lcd.clear();
  lcd.setCursor(0, 0);

  aux = 1;
  auxR = 0;
  cont = 0;
  enRango = false;
  clasificable = false;
  adentro = false;

  //------------------pin1-------------------------

  raw1 = analogRead(pin1);

  girarRodillo(45);

  auxR = inRange(1);

  caster = auxR;
  auR = 0;
  
  Serial.print("auR: ");
  Serial.println(auR);
  if (auxR >= 100.00 && auxR <= 5600.00) {

    while (caster / 10 >= 1 ) {
      caster /= 10;
      cont++;
    }

    if (auxR >= 9.5 * pow(10, cont)) {
      cont++;
    }
    cont++;
    enRango = true;

    Serial.print("Exponente: ");
    Serial.println(cont);
    aux = pow(10, cont);

    adentro = true;
    rangos(aux);

    clasificable = imprimidor(aux, 1);
  }
  //------------------pin2---------------------------


  if (!adentro) {
    girarRodillo(45);

    raw10 = analogRead(pin2);
    auxR = inRange(2);
    //auR = (int)auxR;
    caster = auxR;
    auR = 0;

    Serial.print("auR: ");
    Serial.println(auR);

    if (auxR > 5600.00 && auxR <= 82000.00) {
      while (caster / 10 >= 1) {
        caster /= 10;
        Serial.print("caster:");
        Serial.println(caster);
        cont++;
      }

      Serial.print("auR: ");
      Serial.println(auR);

      if (auxR >= 9.5 * pow(10, cont)) {
        cont++;
      }
      cont++;
      enRango = true;

      Serial.print("Exponente: ");
      Serial.println(cont);
      
      //aux = pow(10, cont);
      int contador = cont;
      while(contador - 1  > 0){
        
        aux *= 10;
        contador--;
        Serial.print("aux: ");
        Serial.println(aux);
        Serial.print("contador: ");
        Serial.println(contador);
        
      }
      Serial.print("FUERA DEL WHILE");

      
      adentro = true;
      rangos(aux);
      clasificable = imprimidor(aux, 2);
    }
  }
  //------------------pin3---------------------------

  if (!adentro) {
    girarRodillo(45);

    raw100 = analogRead(pin3);

    auxR = inRange(3);
    //auR = (int) auxR;
    
    caster = auxR;
    auR = 0;
    Serial.print("auR: ");
    Serial.println(auR);

    if (auxR > 82000.00 && auxR <= 820000.00) {
      while (caster / 10 >= 1) {
        caster /= 10;
        cont++;
      }

      if (auxR >= 9.5 * pow(10, cont)) {
        cont++;
      }
      enRango = true;
      cont++;
      Serial.print("Exponente: ");
      Serial.println(cont);
      aux = pow(10, cont);

      adentro = true;
      rangos(aux);
      clasificable = imprimidor(aux, 3);
    }
  }

  if (enRango && clasificable) {

    Serial.print("El valor de la resistencia es: ");
    Serial.println(auxR);

    lcd.clear();

    lcd.setCursor(0, 0);
    lcd.print("Res:    ");
    lcd.print(auxR);

    Serial.print("La resistencia fue ubicada en la caja número: ");
    Serial.println(cajaBase);

    lcd.setCursor(0, 1);
    lcd.print("A caja: ");
    lcd.print(cajaBase);

  } else if (enRango && !clasificable) {

    Serial.print("\n-La resistencia es inclasificable, pero está en el rango de: ");
    Serial.print(valores[0][0]);
    Serial.print(" a ");
    Serial.print(valores[12][1]);
    Serial.print("-\n");

    lcd.clear();
    lcd.setCursor(0, 0);

    lcd.print("Inclasificable");
    lcd.setCursor(0, 1);
    lcd.print("Rango: ");
    lcd.print(valores[0][0]);
    lcd.setCursor(10, 1);
    lcd.print(valores[12][1]);

  } else if (!enRango) {

    Serial.println("\n\t-La resistencia está fuera de todo rango-\n");

  }
}
